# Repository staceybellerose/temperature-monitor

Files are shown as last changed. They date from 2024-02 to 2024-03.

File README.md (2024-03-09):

# Outdoor Temperature Monitor

Temperature Monitor using BMP388 and AM2320B sensors on a Raspberry Pi Zero WH.

<!--
SPDX-FileCopyrightText: © 2022 Stacey Adams <stacey.belle.rose@gmail.com>
SPDX-License-Identifier: MIT
-->

## Hardware Installation

### Equipment List

* [Raspberry Pi Zero WH](https://www.adafruit.com/product/3708) or [Raspberry Pi Zero W](https://www.adafruit.com/product/3400)
* [SparkFun Qwiic SHIM for Raspberry Pi](https://www.sparkfun.com/products/15794)
* [STEMMA QT / Qwiic JST SH 4-pin Cable with Premium Female Sockets](https://www.adafruit.com/product/4397)
* [Adafruit BMP388 sensor board](https://www.adafruit.com/product/3966)
* Project box: [LKG Philmore Project Box PB110 - Microcenter SKU 591057](https://www.microcenter.com/product/662080/lkg-philmore-project-box-pb110)
* microSD card: [Micro Center 16GB microSDHC Card Class 10 Flash Memory Card - Microcenter SKU 415141](https://www.microcenter.com/product/486146/micro-center-16gb-microsdhc-card-class-10-flash-memory-card-with-adapter)
* [AM2320B](https://www.jemrf.com/products/am2320b-dht22-digital-temperature-and-humidity-sensor) Temperature/Humidity Sensor, bought on eBay.

#### Power supply options

* Inland 5.25V 2.4A Wall Power Supply for Raspberry Pi: [Microcenter SKU 422766](https://www.microcenter.com/product/486582/inland-525v-24a-wall-power-supply-for-raspberry-pi-and-asus-tinker-board)
* Inland 5.2V 2.4A Micro USB Power Supply: [Microcenter SKU 279737](https://www.microcenter.com/product/637777/inland-52v-24a-micro-usb-power-supply)

### Miscellaneous Parts and Tools

* 6x2 Pin female headers (used to hold the Qwiic SHIM down)
* 2x6 or 2x20 pin male header (if using Raspberry Pi Zero W)
* [Weatherproof Electrical Outlet Cover](https://www.homedepot.com/p/304669863)
* Dremel™ rotary tool, to cut holes in project box for power and sensor wires
* Hot Glue, to seal wire outlets in project box
* Velcro Strip, to mount project box on wall
* Soldering iron, to solder the AM2320B wires to the BMP388 board

### Wiring Diagram

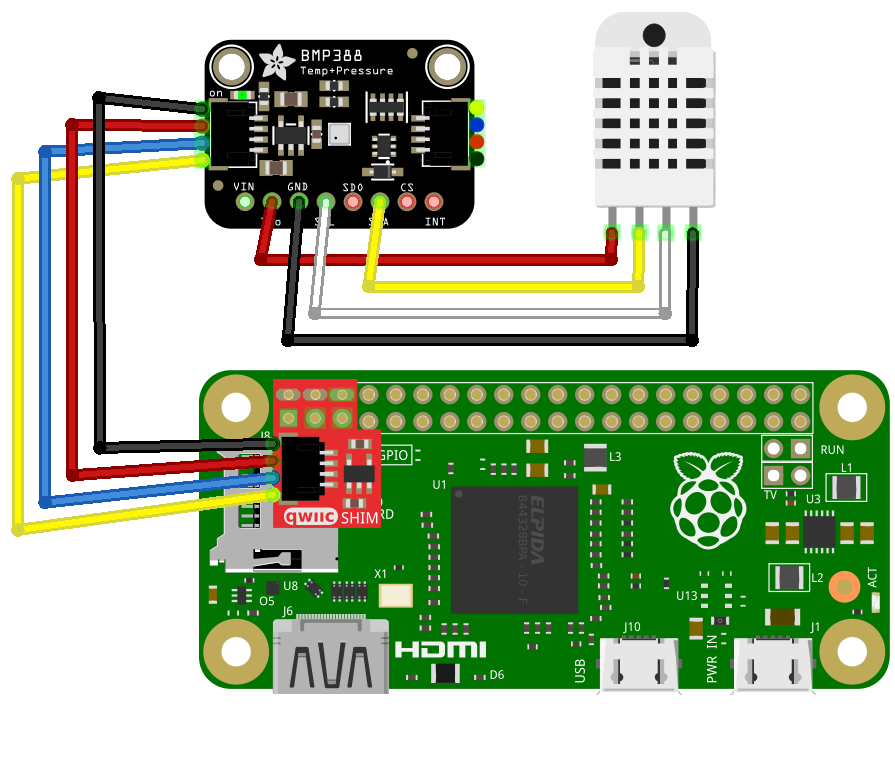
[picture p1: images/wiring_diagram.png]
wiring


## Software Installation

Clone this repo to the Raspberry Pi Zero WH:

```bash
git clone https://github.com/staceybellerose/temperature-monitor.git
```

Create an [Adafruit.IO](https://io.adafruit.com/) developer account.

Copy `config.ini.sample` to `config.ini` and add your Adafruit.IO username and
key.

If you want to record your location data, there are two options:

1. Manually add your latitude and longitude to `config.ini`.

1. Create a [Positionstack](https://positionstack.com/) developer account, and
add your PositionStack.com access key to `config.ini`.

Install the necessary modules into a virtual environment:

```bash
python3 -m venv venv
venv/bin/pip3 install -r requirements.txt
```

Run the script:

```bash
venv/bin/python3 main.py
```

### Temperature Monitor Service Run at Boot

Edit `bin/temp-monitor.sh` to reflect the absolute path of this project and the
path of the python virtual environment.

Install the startup script:

```bash
sudo cp bin/temp-monitor.sh /usr/local/bin/
```

Copy the systemd unit file to the appropriate folder:

```bash
sudo mkdir -p /usr/local/lib/systemd/system/ # this folder may not exist yet
sudo cp temp-monitor.service /usr/local/lib/systemd/system/
```

Activate the service:

```bash
sudo systemctl daemon-reload
sudo systemctl enable temp-monitor.service
sudo systemctl start temp-monitor.service
```

View the output of the service to confirm that it is working:

```bash
journalctl -u temp-monitor.service -f
```

#### Still To Do

Need to make the filesystem read-only so that the microSD card doesn't corrupt
itself after running for several months.

## Images

Project box with components placed, ready to be sealed:

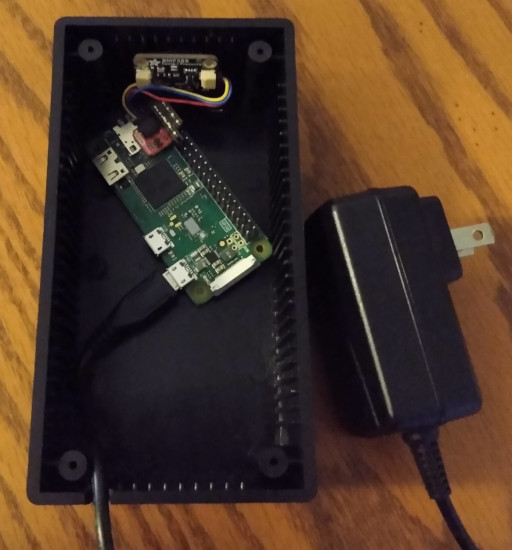
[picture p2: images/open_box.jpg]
open box


Closed project box, with velcro strip applied:

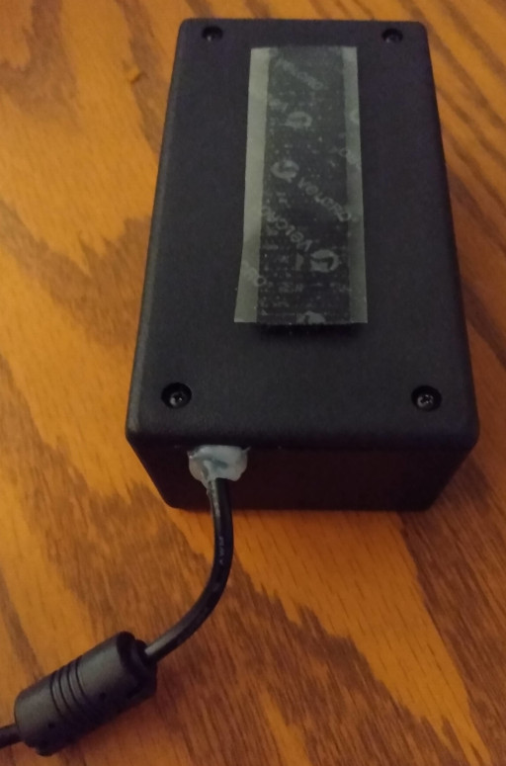
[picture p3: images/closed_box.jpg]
closed box


Project box after adding AM2320B sensor, mounted on left side with nut and bolt:

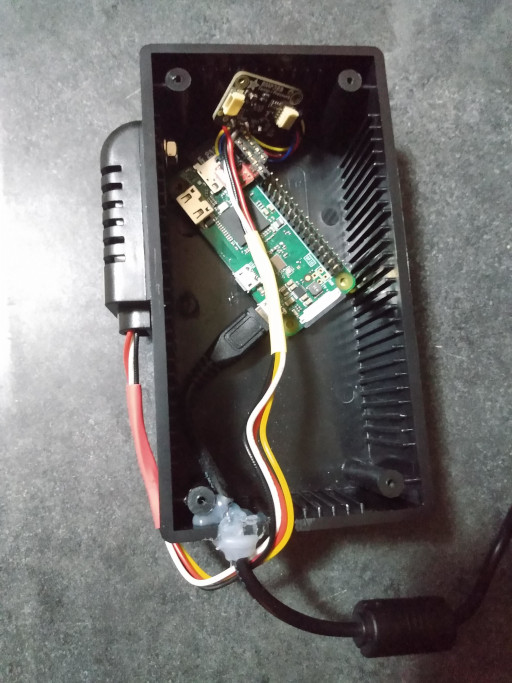
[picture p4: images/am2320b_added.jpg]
AM2320B added


Hot glue was applied all around the nut and the AM2320B wiring before closing the project box.

Project box mounted to exterior wall:

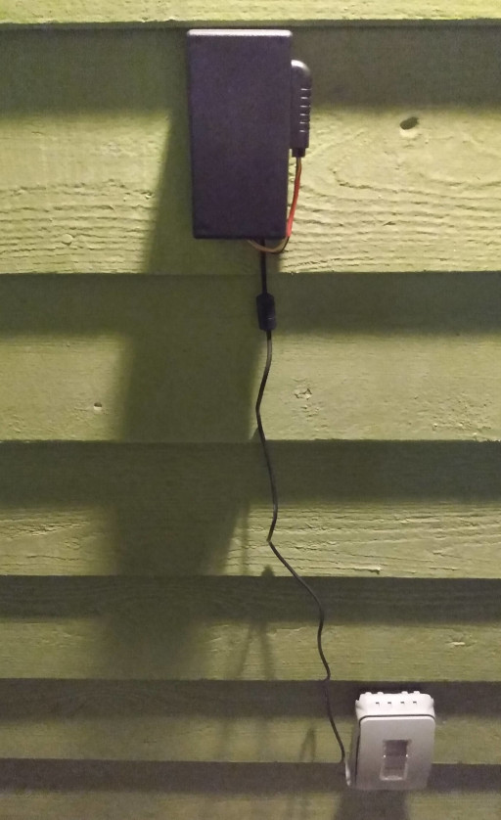
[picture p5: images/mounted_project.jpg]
mounted project


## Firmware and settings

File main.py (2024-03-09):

# SPDX-FileCopyrightText: © 2024 Stacey Adams <stacey.belle.rose@gmail.com>
# SPDX-License-Identifier: MIT

"""
Temperature Monitor.
"""

import dataclasses
import signal
import sys
import time
from typing import NoReturn

import board
import adafruit_bmp3xx
import adafruit_am2320

from eprint import eprint
from settings import Settings
from positionstack import Positionstack
from opentopodata import OpenTopoData
from aio_logger import AIOLogger


@dataclasses.dataclass
class Sensors:
    """
    Collection of sensors used in this project.
    """
    bmp388: adafruit_bmp3xx.BMP3XX_I2C
    am2320: adafruit_am2320.AM2320


class TemperatureMonitor:
    """
    Temperature Monitor.
    """
    _FEED_GROUP = "outdoor"
    _TEMPERATURE_FEED = "temperature"
    _PRESSURE_FEED = "pressure"
    _HUMIDITY_FEED = "humidity"
    _PRECISION = 1

    def __init__(self) -> None:
        self.settings = Settings('config.ini')
        self.settings.dump()
        self.aio_logger = AIOLogger(
            self.settings.adafruit_username,
            self.settings.adafruit_key,
            group_name=self._FEED_GROUP
        )
        if self.settings.send_location:
            if self.settings.has_location():
                latitude = self.settings.latitude
                longitude = self.settings.longitude
            else:
                positionstack = Positionstack(self.settings.geocoding_token)
                latitude, longitude, _label = positionstack.forward_geocode(
                    self.settings.query,
                    self.settings.region,
                    self.settings.country
                )
            otd = OpenTopoData()
            elevation = otd.get_elevation(latitude, longitude)
            self.aio_logger.set_metadata(latitude, longitude, elevation)
        self.aio_logger.get_feed(self._TEMPERATURE_FEED)
        self.aio_logger.get_feed(self._PRESSURE_FEED)
        self.aio_logger.get_feed(self._HUMIDITY_FEED)
        i2c = board.I2C()
        self.sensors = Sensors(
            adafruit_bmp3xx.BMP3XX_I2C(i2c),
            adafruit_am2320.AM2320(i2c)
        )

    def log_single_datum(self, datum: float, feed: str) -> None:
        """
        Log a single sensor datum to an Adafruit.IO feed.
        """
        rounded = round(datum, self._PRECISION)
        self.aio_logger.log(feed, rounded)

    def log_data(self) -> None:
        """
        Log the current sensor data.
        """
        try:
            temp2 = self.sensors.am2320.temperature
            self.log_single_datum(temp2, self._TEMPERATURE_FEED)
            humidity = self.sensors.am2320.relative_humidity
            self.log_single_datum(humidity, self._HUMIDITY_FEED)
            pressure = self.sensors.bmp388.pressure
            self.log_single_datum(pressure, self._PRESSURE_FEED)
            eprint(
                f"Sensor data recorded: {temp2:.1f} °C, {humidity:.1f} %RH, {pressure:.1f} hPa"
            )
        except OSError as exc:
            eprint("Unable to read sensor.", exc.strerror, sep="\n")


def main() -> NoReturn:
    """
    Entry point function when run from command line.
    """
    def signal_handler(*args):
        """
        Handle various signals
        """
        signum = args[0]
        eprint(f'Handling signal {signum} ({signal.Signals(signum).name}).')
        if signum in (signal.SIGINT, signal.SIGTERM):
            sys.exit(0)
        else:
            eprint("Unknown signal received.")

    monitor = TemperatureMonitor()
    signal.signal(signal.SIGINT, signal_handler)
    signal.signal(signal.SIGTERM, signal_handler)
    while True:
        monitor.log_data()
        time.sleep(60)


if __name__ == '__main__':
    main()

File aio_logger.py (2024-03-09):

# SPDX-FileCopyrightText: © 2022, 2024 Stacey Adams <stacey.belle.rose@gmail.com>
# SPDX-License-Identifier: MIT

"""
Wrapper class for Adafruit.IO.
"""

from datetime import datetime, timezone
import dataclasses
import json
from typing import Any, Optional

from urllib3.util import Retry
from requests import RequestException, Session
from requests.adapters import HTTPAdapter
from Adafruit_IO import Client, Group, Feed, AdafruitIOError

from eprint import eprint


@dataclasses.dataclass
class Metadata:
    """
    Metadata to record at Adafruit.IO along with data from feed.
    """
    lat: Optional[float]
    lon: Optional[float]
    ele: Optional[float]


class AIOClient(Client):
    """
    Adafruit.IO Client wrapper to better handle request retries.
    """
    def __init__(self, username, key, proxies=None, base_url='https://io.adafruit.com'):
        super().__init__(username, key, proxies, base_url)
        self.session = Session()
        self.session.proxies = proxies
        retry_strategy = Retry(
            total=5,
            backoff_factor=1,
            status_forcelist=[429, 500, 502, 503, 504],
            allowed_methods=["HEAD", "GET", "PUT", "POST", "DELETE", "OPTIONS", "TRACE"]
        )
        self.session.mount('https://', HTTPAdapter(max_retries=retry_strategy))
        self.session.mount('http://', HTTPAdapter(max_retries=retry_strategy))

    def _build_headers(self, content_type: Optional[str] = None):
        headers = {'X-AIO-Key': self.key}
        if content_type is not None:
            headers['Content-Type'] = content_type
        return headers

    def _get(self, path, params=None):
        response = self.session.get(
            self._compose_url(path),
            headers=self._build_headers(),
            params=params
        )
        self._last_response = response
        self._handle_error(response)
        return response.json()

    def _post(self, path, data):
        response = self.session.post(
            self._compose_url(path),
            headers=self._build_headers('application/json'),
            data=json.dumps(data)
        )
        self._last_response = response
        self._handle_error(response)
        return response.json()

    def _delete(self, path):
        response = self.session.delete(
            self._compose_url(path),
            headers=self._build_headers('application/json')
        )
        self._last_response = response
        self._handle_error(response)


class AIOLogger:
    """
    Adafruit.IO API Data Logger.
    """
    def __init__(self, aio_user: str, aio_key: str, group_name: str = "Default"):
        """
        Parameters
        ----------
        aio_user: Username for Adafruit.IO.
        aio_key: Authentication Key for Adafruit.IO.
        group_name: Name of group to use at Adafruit.IO.
        """
        self.aio = AIOClient(aio_user, aio_key)
        self.group = self.get_feed_group(group_name)
        self.feeds = self.aio.feeds()
        self.metadata: Optional[Metadata] = None

    def set_metadata(
        self,
        latitude: Optional[float] = None,
        longitude: Optional[float] = None,
        elevation: Optional[float] = None
    ):
        """
        Set the metadata to use when posting to Adafruit.IO.

        Parameters
        ----------
        latitude: Latitude of the sensor.
        longitude: Longitude of the sensor.
        elevation: Elevation of the sensor.
        """
        self.metadata = Metadata(latitude, longitude, elevation)

    def get_feed_group(self, group_name: str) -> Group:
        """
        Get a Feed Group based on the group_name parameter, creating one if needed.

        Parameters
        ----------
        group_name: The name of the group to retrieve/create.

        Returns
        -------
        A Feed Group object.
        """
        group_list: list[Group] = self.aio.groups()
        for group in group_list:
            if group.name == group_name:
                return group
        # didn't find the feed group, so create it
        group = Group(name=group_name)
        return self.aio.create_group(group)

    def get_feed(self, feed_name: str) -> Feed:
        """
        Get a Feed object based on the feed_name parameter, creating one if needed.

        The Feed will be associated with our feed group.

        Parameters
        ----------
        feed_name: The name of the feed to retrieve/create.

        Returns
        -------
        A Feed object.
        """
        feed_key = f"{self.group.key}.{feed_name}"
        feed_list: list[Feed] = self.aio.feeds()
        for feed in feed_list:
            if feed.key == feed_key:
                return feed
        # didn't find the feed, so create it
        feed = Feed(name=feed_name)
        return self.aio.create_feed(feed, group_key=self.group.key)

    def log(self, feed_name: str, datapoint: Any):
        """
        Log data to Adafruit.IO.

        Parameters
        ----------
        feed_name: The name of the feed to which the data belongs.
        datapoint: The data to add to the feed.
        """
        if self.metadata is not None:
            metadata = dataclasses.asdict(self.metadata)
            metadata['created_at'] = datetime.now(timezone.utc).isoformat()
        else:
            metadata = None
        feed_key = f"{self.group.key}.{feed_name}"
        try:
            self.aio.send(feed_key, datapoint, metadata)
        except (AdafruitIOError, RequestException):
            eprint(f"WARN: Unable to transmit data ({datapoint}) to feed {feed_key} - skipped.")

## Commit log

2024-02-12 Add image to README
    [wiring_diagram.fzz]
2024-02-13 Location is now optional. No longer require Positionstack account if not sending location, or if using location stored in config.ini.
    [aio_logger.py, main.py, positionstack.py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]
2024-02-28 fix type hinting issues reported by mypy
    [aio_logger.py, get_api.py, opentopodata.py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]
2024-02-28 fix bug with AIO Logger initialization
    [main.py]
2024-02-28 Add new sensor to system (AM2320)
2024-02-28 Update README with new photos and information about new AM2320B sensor
    [wiring_diagram.fzz]
2024-03-09 Fix lint errors and clean up licensing
    [aio_logger.py, get_api.py, main.py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]
